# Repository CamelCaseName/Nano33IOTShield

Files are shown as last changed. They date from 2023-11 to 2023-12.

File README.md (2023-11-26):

# Nano33IOTShield
A shield for the Arduino nano 33 IOT to shifts it's GPIO from 3.3v to 5v with an integrated HUB75 plug

See the [bill of materials](/BOM.txt) for what to get.

The [HUB75nano](https://github.com/CamelCaseName/HUB75nano) library will be updated to support this hat and arduino combination.

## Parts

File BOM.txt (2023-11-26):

To build this, you need:
- the pcb
- 2x TXB0108
- 1x 22uF 1206 SMD capacitor
- 1x 10uF 1206 SMD capacitor
- 2x 100+ kOhm 1206 SMD resistor
- 1x 10uH 1008 SMD Inductor
- 2x 1x15 2.54mm pitch female THT sockets
- 1x 2x8 2.54mm pitch male THT IDC plug
- 1x JST S2B-EH 90°
- 1x LTC3525-5
- 1x DIP SWx2 COPAL CHS-02A P1.27mm

Solder everything together according to the schematic and run the software on the arduino. Connect your Panel and done.

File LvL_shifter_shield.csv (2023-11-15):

# | Reference | Qty | Value | Footprint | DNP
1 | C1, C2 | 2 | 0.1u | Capacitor_SMD:C_1206_3216Metric_Pad1.33x1.80mm_HandSolder
2 | J1 | 1 | Conn_02x08_Counter_Clockwise | Connector_PinSocket_2.54mm:PinSocket_2x08_P2.54mm_Vertical
3 | J2, J3 | 2 | Conn_01x15_Socket | Connector_PinSocket_2.54mm:PinSocket_1x15_P2.54mm_Vertical
4 | J4 | 1 | Power | Connector_JST:JST_EH_S2B-EH_1x02_P2.50mm_Horizontal
5 | R1, R2 | 2 | r=50k | Resistor_SMD:R_1206_3216Metric_Pad1.30x1.75mm_HandSolder
6 | U1, U2 | 2 | TXB0108DQSR | Package_SON:USON-20_2x4mm_P0.4mm

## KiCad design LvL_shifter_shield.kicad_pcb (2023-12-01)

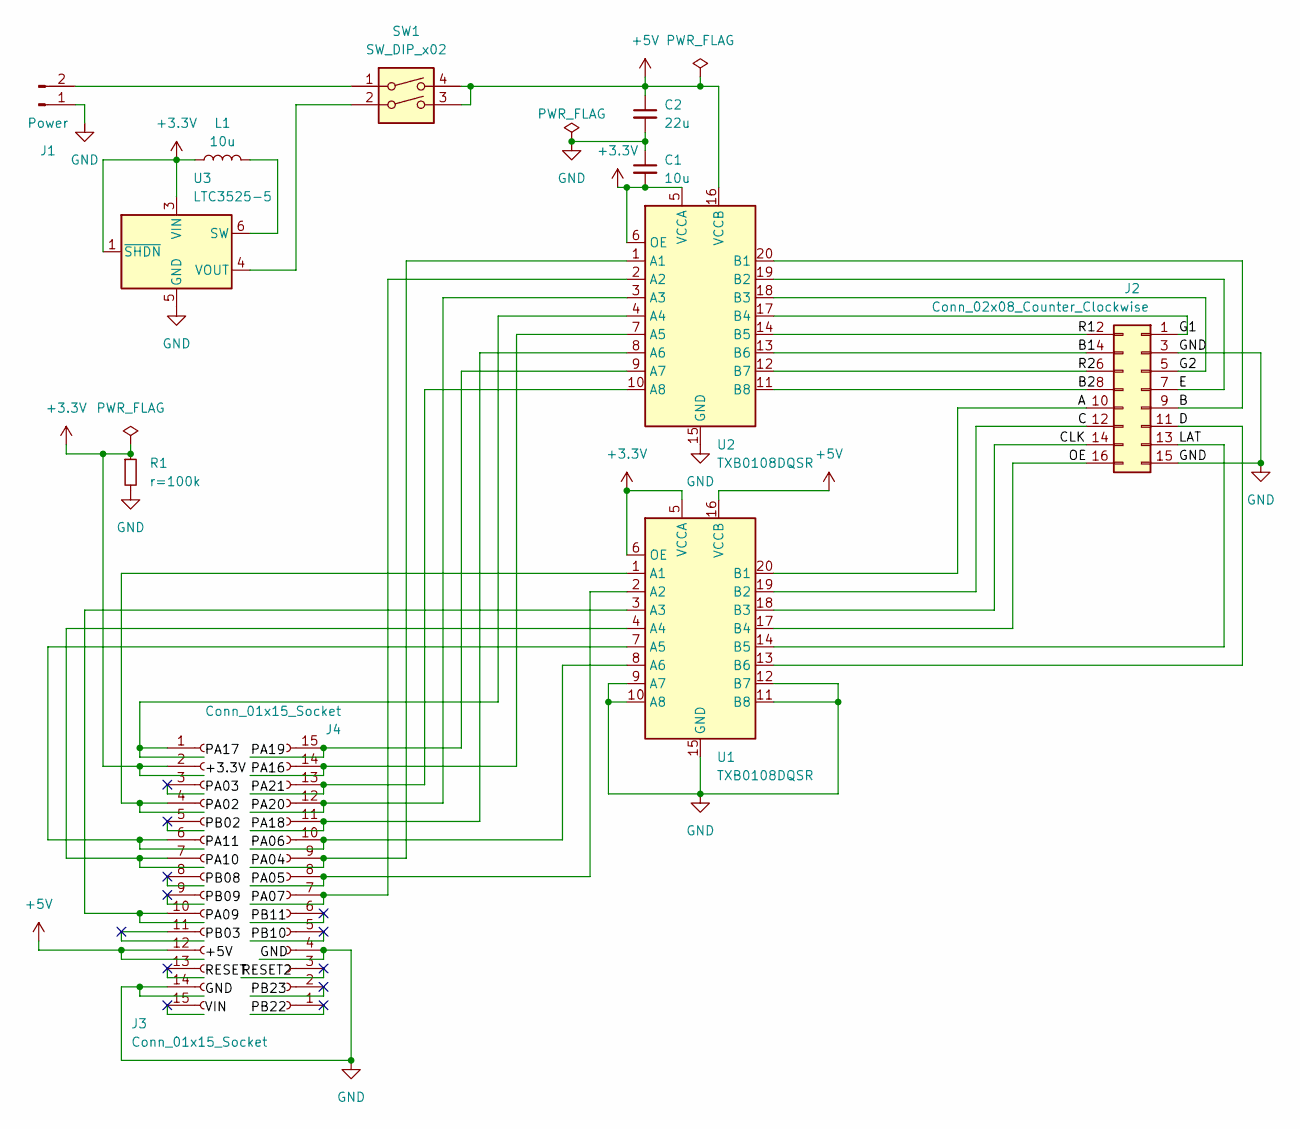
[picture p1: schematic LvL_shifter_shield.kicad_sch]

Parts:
C1: 10u; C_1206_3216Metric_Pad1.33x1.80mm_HandSolder
C2: 22u; C_1206_3216Metric_Pad1.33x1.80mm_HandSolder
J1: Power; JST_EH_S2B-EH_1x02_P2.50mm_Horizontal
J2: Conn_02x08_Counter_Clockwise; PinSocket_2x08_P2.54mm_Vertical
J3, J4: Conn_01x15_Socket; PinSocket_1x15_P2.54mm_Vertical
L1: 10u; L_1008_2520Metric_Pad1.43x2.20mm_HandSolder
R1: r=100k; R_1206_3216Metric_Pad1.30x1.75mm_HandSolder
SW1: SW_DIP_x02; SW_DIP_SPSTx02_Slide_Copal_CHS-02A_W5.08mm_P1.27mm_JPin
U1, U2: TXB0108DQSR; USON-20_2x4mm_P0.4mm
U3: LTC3525-5; SOT-363_SC-70-6

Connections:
+3.3V: C1.2, J3.2, L1.1, R1.1, U1.5 (VCCA), U1.6 (OE), U2.5 (VCCA), U2.6 (OE), U3.1 (~SHDN), U3.3 (VIN)
+5V: C2.1, J3.12, SW1.3, SW1.4, U1.16 (VCCB), U2.16 (VCCB)
/A: J2.10, U1.20 (B1)
/B: J2.9, U2.20 (B1)
/B1: J2.4, U2.13 (B6)
/B2: J2.8, U2.11 (B8)
/C: J2.12, U1.19 (B2)
/CLK: J2.14, U1.18 (B3)
/D: J2.11, U1.13 (B6)
/E: J2.7, U2.19 (B2)
/G1: J2.1, U2.17 (B4)
/G2: J2.5, U2.18 (B3)
/LAT: J2.13, U1.14 (B5)
/OE: J2.16, U1.17 (B4)
/PA02: J3.4, U1.1 (A1)
/PA03: J3.3
/PA04: J4.9, U2.1 (A1)
/PA05: J4.8, U1.2 (A2)
/PA06: J4.10, U1.8 (A6)
/PA07: J4.7, U2.2 (A2)
/PA09: J3.10, U1.3 (A3)
/PA10: J3.7, U1.4 (A4)
/PA11: J3.6, U1.7 (A5)
/PA16: J4.14, U2.7 (A5)
/PA17: J3.1, U2.4 (A4)
/PA18: J4.11, U2.8 (A6)
/PA19: J4.15, U2.9 (A7)
/PA20: J4.12, U2.3 (A3)
/PA21: J4.13, U2.10 (A8)
/PB02: J3.5
/PB03: J3.11
/PB08: J3.8
/PB09: J3.9
/PB10: J4.5
/PB11: J4.6
/PB22: J4.1
/PB23: J4.2
/R1: J2.2, U2.14 (B5)
/R2: J2.6, U2.12 (B7)
/RESET: J3.13
/RESET2: J4.3
/VIN: J3.15
GND: C1.1, C2.2, J1.1, J2.3, J2.15, J3.14, J4.4, R1.2, U1.9 (A7), U1.10 (A8), U1.11 (B8), U1.12 (B7), U1.15 (GND), U2.15 (GND), U3.2 (GND), U3.5 (GND)
unnamed: J1.2, SW1.1
unnamed: L1.2, U3.6 (SW)
unnamed: SW1.2, U3.4 (VOUT)

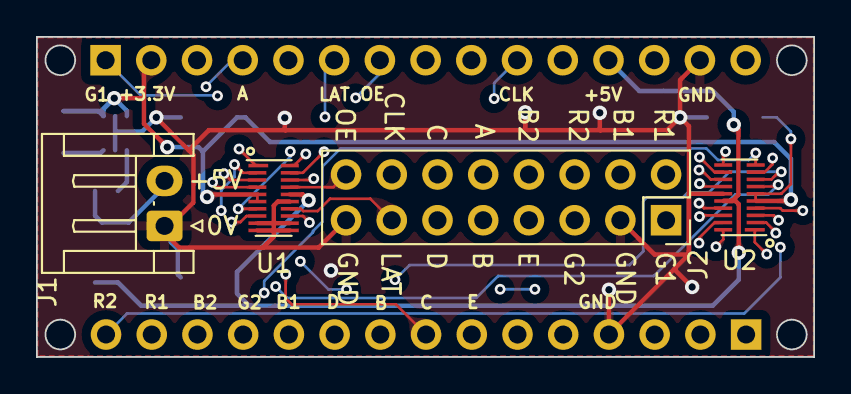
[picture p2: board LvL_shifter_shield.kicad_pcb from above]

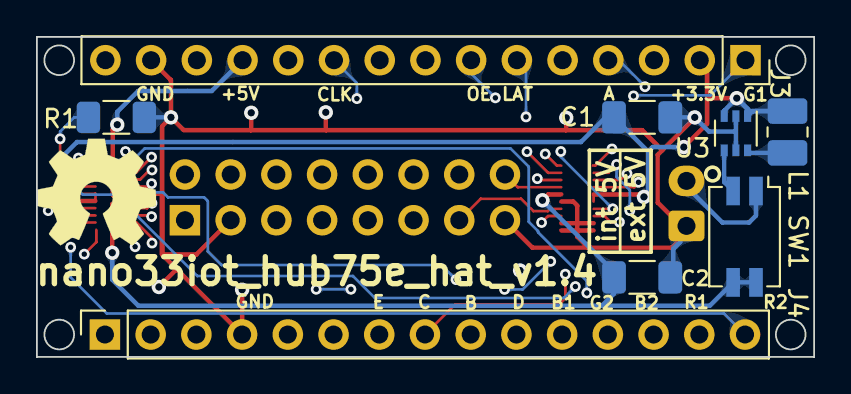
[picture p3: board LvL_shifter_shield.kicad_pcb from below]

Board: 4 copper layers, 43.2 x 17.8 mm, 12 parts (8 on the bottom side), 34 nets.

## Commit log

2023-11-16 Updated silkscreen and added a +5 link to the nano
    [LvL_shifter_shield.kicad_pcb, LvL_shifter_shield.kicad_sch]
2023-11-16 Forgot to set OE high when power is connected
    You can work around this with a jumper wire from 3.3v to the OE side of the R1 and R2
    [LvL_shifter_shield-B_Cu.gbr, LvL_shifter_shield-B_Mask.gbr, LvL_shifter_shield-B_Paste.gbr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]
2023-11-17 Updated version number, added open hardware logo
    [LvL_shifter_shield.kicad_pcb, LvL_shifter_shield.kicad_sch]
2023-11-26 switched pin PA03 and PA02, added internal 5V
    the dip switch can be used to get external 5v, internal or when none is selected the usb 5v from the arduino
    [LvL_shifter_shield-B_Cu.gbr, LvL_shifter_shield-B_Mask.gbr, LvL_shifter_shield-B_Paste.gbr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]
2023-12-01 fixed drill files
    [LvL_shifter_shield-B_Cu.gbr, LvL_shifter_shield-B_Mask.gbr, LvL_shifter_shield-B_Paste.gbr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]
